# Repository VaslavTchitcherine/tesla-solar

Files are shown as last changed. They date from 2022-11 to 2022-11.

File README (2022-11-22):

TESLA MODULE SOLAR POWER SYSTEM

This describes how to use Tesla Model S battery modules in an offgrid
solar power system, comprised of:

1) Any number (between 1 and 63) of Tesla Model S battery modules connected in parallel.
The prototype system has two modules from a P100D, each 6.4 kWh. 

2) A solar charge controller.
Victron BlueSolar 24V MPPT 100/50 Charge Controller (100V, 50A maximum input).
It is essential that the controller allows you to set the maximum charge voltage
to something suitable for the Tesla modules (i.e. never more than 25.2V).

3) An inverter for AC output.  Modern pure sine wave inverters
are quite efficient.  Ideally you want one with an adjustable
(or no) low voltage cutoff, as the Tesla modules are usable down to about 18V,
lower than many other battery chemistries.

4) Two hall effect current sensors (Allegro ACS758) to measure panel
current and battery current.  The battery current can be positive or negative,
depending on whether the battery is charging or discharging.  Panel current
is never less than zero.

5) A pair of DC solid state relays (Crydom D06D100) to disconnect the panels
if the battery modules are overvoltage, and disconnect the battery modules if they
are undervoltage.

6) A Raspberry Pi Zero W with a custom Pi hat.  Python code on the Pi:
	a) Communicates with the Tesla modules using a 612500 baud serial loop.
	b) Reads current sensors using a 16 bit dual A/D (ADS1115)
	c) Monitors and logs voltages, currents, and battery temperatures.
	d) Serves plots of the logs on a web page (using the dygraphs.js library)
	d) Controls the SSR disconnects via GPIO
	e) Balances batteries at both the module and cell level, by switching in
	   shunt resistors on the Tesla BMS boards when necessary.

7) Optionally, an AC SSR (Opto22 240A45) to disconnect the output of the 
inverter from the load.  Some inverters enter an error state if there
is an AC load when DC input power is applied.  This SSR disconnects the
load from the output of the inverter until several seconds after the
inverter is connected to the battery bank by the respective DC SSR.

The Pi is powered directly (through a small fuse) from the
battery modules, using an LM2596-based buck converter.
It is important that the Pi remain powered through
an undervoltage condition, so that it can close the SSR to reconnect the
battery modules to the inverter once they are sufficiently charged so that
they are no longer undervoltage. 

(BLOCK DIAGRAM)
(PHOTOS of system and control box)

Tesla Battery Modules
---------------------

All Telsa Model S battery modules have 6 series-connected groups
of a large number of 18650 LiOn cells in parallel.
For example, the P100D module has 516 18650 LiOn cells per module, connected 6s86p.

A fully charged 18650 cell is 4.2V, so 4.2*6 = 25.2V is the maximum voltage
of a fully charged module.  It is better to set the float voltage on the
Victon charge controller for a lower voltage (e.g. 24.2V) to both
allow some headroom for unbalanced cells and to avoid stressing the cells.
The Panasonic NCR18650B data sheet shows a knee at around 3.0V on the
discharge characteristics graph, so 3.0*6 = 18V can be considered the minimum usable voltage of a module.

The Tesla module has a BMS board, containing:
C8051F536 microprocessor
Silicon Labs 8642ED RF isolator
TI BQ76PL536A Lithium ion battery monitor (for 6 cells)
158 ohm resistors, 4 in parallel, for a 39.5 ohms of bleed for balancing

These modules communicate via 612500 baud serial, with the serial connection
arranged in a loop (Wiring2.png).  What is meant by a loop?
Each module receives serial data on RX (pin 2) and transmits it on TX (pin 4).
There are two separate channels that are not connected to each other.
So any data intended for the entire system goes to the first module, which then retransmits it
from its TX to the input RX on the next module in the chain.

Connectors for Tesla modules are:
	Molex 15-97-5101 CONN RCPT 10POS DUAL MINI-FIT (Digikey WM4772-ND)
and the pins are:
	Molex 39-00-0038 CONN TERM FEMALE 18-24AWG TIN (Digikey WM2501CT-ND)

Using the Raspberry Pi (Pi Zero W, Pi3, Pi3B+) UART
---------------------------------------------------

UART0_TXD is GPIO 14, pin 8 on GPIO header
UART0_RXD is GPIO 15, pin 10 on GPIO header

By default the the primary UART (/dev/serial0) is used for a console.
Use the raspi-config utility to disable this.
Select option 5, Interfacing options, then option P6, Serial, and select No.

The BCM2837 on a recent Pi has two UARTS, but the mini UART is not suitable for
high speed serial communication, having too small a buffer and variable frequency.
To use the PL011 UART instead of the mini UART, add these lines to the /boot/config.txt file:
        dtoverlay=pi3-disable-bt
        enable_uart=1
This disables the Bluetooth module and maps the PL011 UART onto GPIO pins 14 and 15,
which appears as /dev/serial0 (a symbolic link to /dev/ttyAMA0).
Note the pi4 instructions are different:
https://di-marco.net/blog/it/2020-06-06-paspberry_pi_3_4_and_0_w_serial_port_usage/

Also, the Pi is 3.3V, and needs to interface to 5V RS232 serial levels on the Tesla modules.
For this, we use the circuit from the SparkFun bidirectional logic level converter
(https://www.sparkfun.com/products/12009) which uses a BSS138 MOSFET with pullups to
perform the level conversion.

References:
https://www.raspberrypi.org/documentation/configuration/uart.md
https://raspberrypi.stackexchange.com/questions/45570/how-do-i-make-serial-work-on-the-raspberry-pi3-pi3b-pizerow

A/D conversion
--------------

To use the ADS1115, the I2C interface has to be enabled on the Pi.
Details on how do do this using raspi-config are here:
    https://learn.adafruit.com/adafruits-raspberry-pi-lesson-4-gpio-setup/configuring-i2c

We use the Adafruit_ADS1x15 library to communicate with the ADS1115:
	sudo apt-get update
	sudo apt-get install -y python-smbus
	sudo apt-get install i2c-tools
	sudo apt-get install build-essential python-dev python-smbus git
	cd ~
	git clone https://github.com/adafruit/Adafruit_Python_ADS1x15.git
	cd Adafruit_Python_ADS1x15
	sudo python setup.py install

See:
	https://learn.adafruit.com/adafruit-4-channel-adc-breakouts
	https://github.com/adafruit/Adafruit_Python_ADS1X15
	https://learn.adafruit.com/raspberry-pi-analog-to-digital-converters/ads1015-slash-ads1115

DCDC SSR Disconnects
--------------------

A Crydom D06D100 DCDC solid state relay disconnects the panels if an overvoltage condtion
should occur (e.g. misconfiguration or failure of the charge controller).
And another D06D100 is used to disconnect the Tesla modules if an undervoltage condtion
should occur (e.g. too much power consumption or insufficient sunshine).

The SSRs dissipate less power than would
mechanical contactors, except briefly during infrequent conditions of very high current draw.

A mechanical contactor such as a Gigavac of suitable current capacity draws 0.28 A for a
24 VDC coil voltage, i.e. 6.7 W at all times.
With 0.005 ohm Rds(on) the Crydom D06D100 SSR relay at draws
	I^2R = 100 * 100 * 0.005 = 12.5 W
at 100A.  But in practice I never pull more than 40A from my batteries,
and generally only a few amps.   So this Crydom DC SSR (which I
understand to be a pair of mosfets with optoisolated driver in a
convenient package) wastes less power than keeping the electromagnet for
a contactor powered.

Note that the Crydom D06D100 is expensive, but I would not trust a
(possibly counterfeit) Fotek to handle the current.

Battery Balancing
-----------------

Despite widespread disinformation and confusion on the subject, battery
balancing is simple.

The Tesla BMS board has shunt resistors, one per cell, which can be independently switched in to 
bleed charge from any of the 6 cells in a battery module.   This "top balancing" should be done whenever
any cell's voltage is sufficiently much higher than that of the second
highest cell in the module.

Analogously, at a module level, all 6 bleed resistors for a module should be
switched in when the voltage for that module is sufficiently much higher than that of the second
highest module.

This balancing is performed by the Python code, voltage thesholds for balancing are
parameters stored in global variables.

Logging and Plotting
--------------------

The Python code writes 3 log files, the names of which must be supplied as positional
command line parameters.

This first of these log files is a CSV file, fields of which are respectively:
datetime in ISO format (YYYY-MM-DD HH:MM:SS)
	module 1 Soc (%)
	module 1 Voltage (V)
	module 1 Temperature 1 (degrees C)
	module 1 Temperature 2 (degrees C)
	module 1 maximum cell imbalance (V)
	module 2 Soc (%)
	module 2 Voltage (V)
	module 2 Temperature 1 (degrees C)
	module 2 Temperature 2 (degrees C)
	module 2 maximum cell imbalance (V)
	.
	.
	.
		module n Soc (%)
	module n Voltage (V)
	module n Temperature 1 (degrees C)
	module n Temperature 2 (degrees C)
	module n maximum cell imbalance (V)
	battery current (A)
	panel current (A)

The second log file is blank delimited file, with a timestamp and fields for the voltage of each cell.

The third log file contains warnings, such as over and undervoltage conditions.

Plots of fields the first log file can be made using the dygraphs.js library (http://dygraphs.com).
Specify /var/www/html/log.csv as the first command line argument to tesla.py and use
index.html as the home page.

Here is sample output.
You can see I had 3 espressos today.

Pi Hat
------

Eagle files and BOM with Digikey part numbers for the Pi Hat.

Thanks
------

Thanks to everyone who did the hard work of reverse engineering the Tesla modules, and
to Ulrich Gall for the original Python code.
http://evtv.me/2017/03/tesla-battery-victory-lap/
https://github.com/collin80/TeslaBMS
https://github.com/jarrod89/TeslaBMS
https://github.com/tomdebree/TeslaBMS

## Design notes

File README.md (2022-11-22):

# tesla-solar
Tesla S modules for off-grid solar power

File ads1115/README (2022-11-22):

hacked examples from /root/Adafruit_Python_ADS1x15/examples

https://learn.adafruit.com/adafruit-4-channel-adc-breakouts
https://github.com/adafruit/Adafruit_Python_ADS1X15
https://learn.adafruit.com/raspberry-pi-analog-to-digital-converters/ads1015-slash-ads1115

Note we have ADDR pin to GND, so i2c slave addr is 1001000 (0x48)

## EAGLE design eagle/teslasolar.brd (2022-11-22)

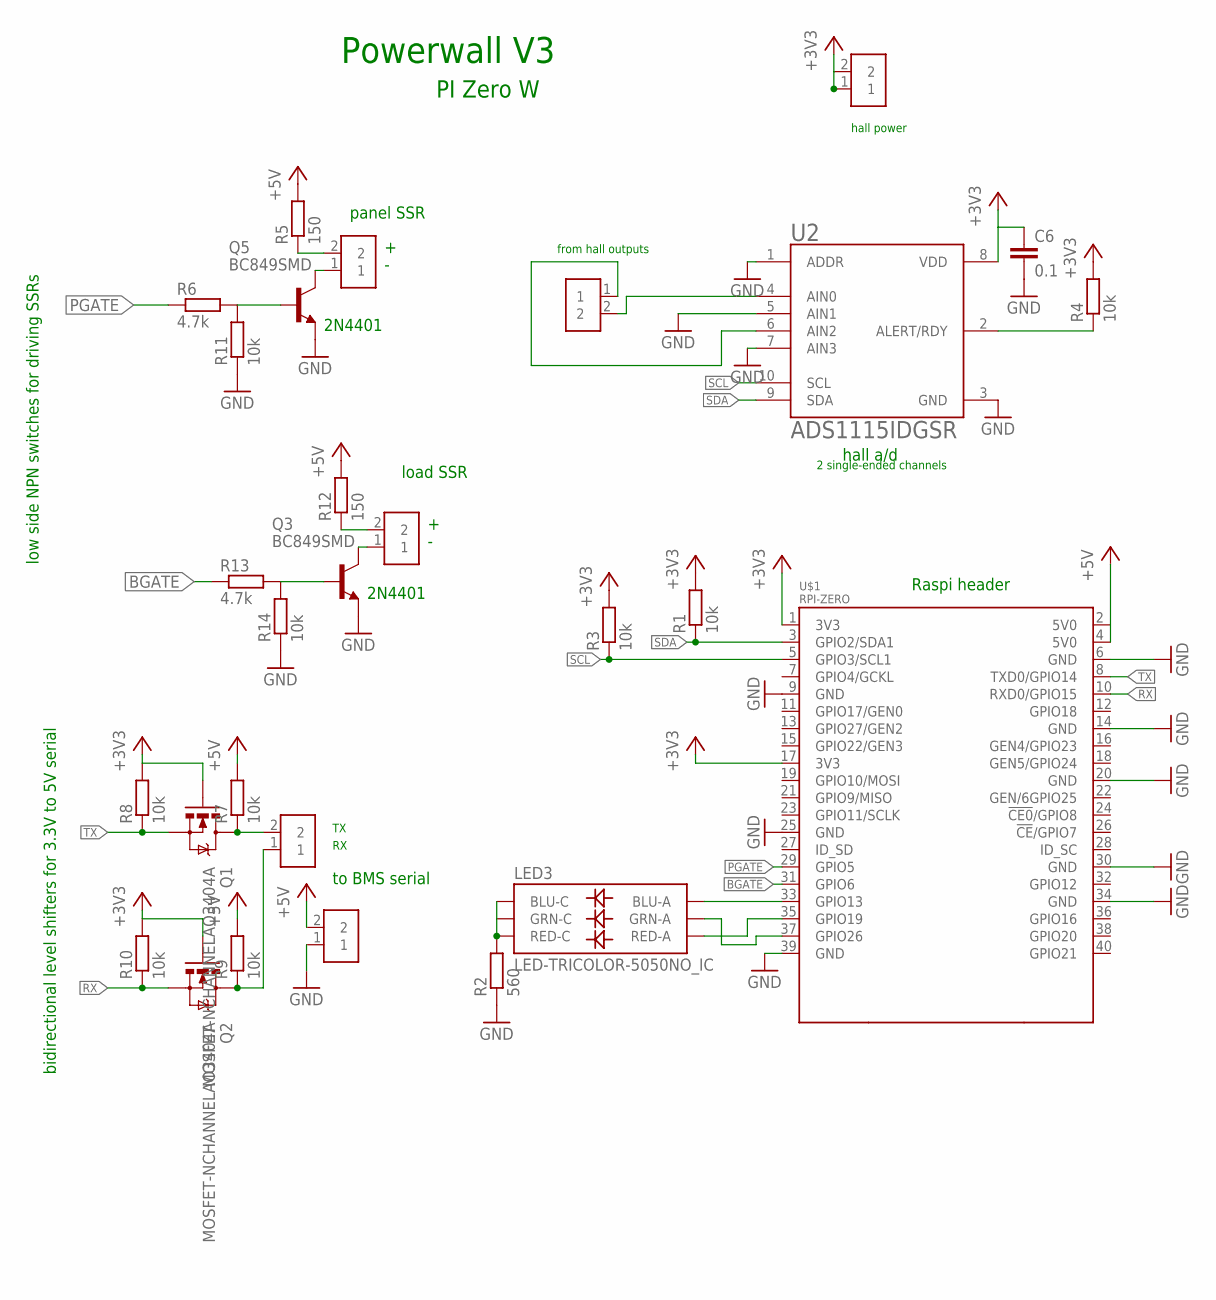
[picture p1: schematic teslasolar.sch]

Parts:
C6: 0.1; C0603
J1, J2, J3, J4, J5, J6: 282834-2; CONN_282834-2
LED3: LED-TRICOLOR-5050NO_IC; LED-TRICOLOR-5050
Q1, Q2: MOSFET-NCHANNELAO3404A; SOT23-3
Q3, Q5: BC849SMD; SOT23-BEC
R1, R3, R4, R7, R8, R9, R10, R11, R14: 10k; R0603
R2: 560; R0805
R5, R12: 150; R0603
R6, R13: 4.7k; R0603
U2: ADS1115IDGSR; SOP50P490X110-10N
U$1: RPI-ZERO; RASPBERRYPI_BASTELSTUBE_V13_RASPI_BOARD_B+_FULL

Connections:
3V3@2: U$1.17 (3V3)
+3V3: C6.1, J4.1, J4.2, Q1.1 (G), Q2.1 (G), R1.2, R3.2, R4.2, R8.2, R10.2, U2.8 (VDD), U$1.1 (3V3)
+5V: J5.2, R5.2, R7.2, R9.2, R12.2, U$1.2 (5V0), U$1.4 (5V0)
BGATE: R13.1, U$1.31 (GPIO6)
GND: C6.2, J5.1, Q3.E, Q5.E, R2.1, R11.1, R14.1, U2.1 (ADDR), U2.3 (GND), U2.5 (AIN1), U2.7 (AIN3), U$1.6 (GND), U$1.9 (GND), U$1.14 (GND), U$1.20 (GND), U$1.25 (GND), U$1.30 (GND), U$1.34 (GND), U$1.39 (GND)
unnamed: LED3.3 (BLU-A), U$1.33 (GPIO13)
unnamed: LED3.2 (RED-A), U$1.35 (GPIO19)
unnamed: LED3.1 (GRN-A), U$1.37 (GPIO26)
unnamed: LED3.4 (BLU-C), LED3.5 (RED-C), LED3.6 (GRN-C), R2.2
unnamed: J3.2, Q1.3 (D), R7.1
unnamed: J3.1, Q2.3 (D), R9.1
unnamed: J1.2, R5.1
unnamed: J6.2, R12.1
unnamed: J1.1, Q5.C
unnamed: Q5.B, R6.2, R11.2
unnamed: J6.1, Q3.C
unnamed: Q3.B, R13.2, R14.2
unnamed: R4.1, U2.2 (ALERT/RDY)
unnamed: J2.1, U2.6 (AIN2)
unnamed: J2.2, U2.4 (AIN0)
PGATE: R6.1, U$1.29 (GPIO5)
RX: Q2.2 (S), R10.1, U$1.10 (RXD0/GPIO15)
SCL: R3.1, U2.10 (SCL), U$1.5 (GPIO3/SCL1)
SDA: R1.1, U2.9 (SDA), U$1.3 (GPIO2/SDA1)
TX: Q1.2 (S), R8.1, U$1.8 (TXD0/GPIO14)

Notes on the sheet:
hall a/d
PI Zero W
to BMS serial
2 single-ended channels
from hall outputs
hall power
Raspi header
panel SSR
Powerwall V3
2N4401
bidirectional level shifters for 3.3V to 5V serial
low side NPN switches for driving SSRs
load SSR

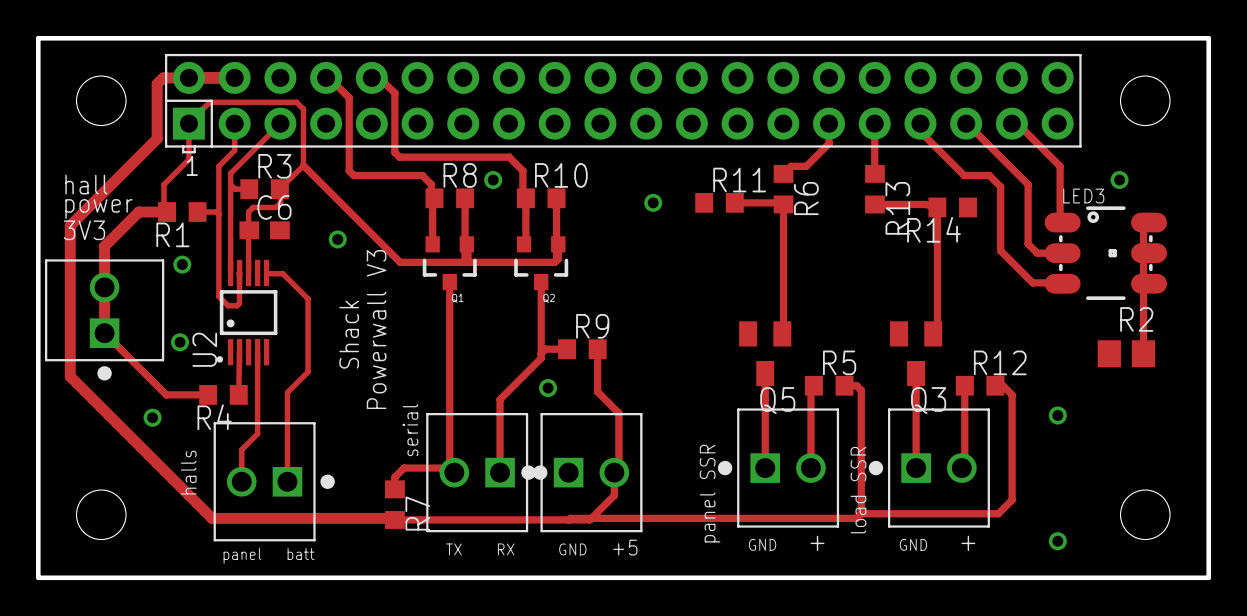
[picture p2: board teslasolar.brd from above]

Board: 2 copper layers, 65.0 x 30.0 mm, 28 parts (0 on the bottom side), 24 nets.

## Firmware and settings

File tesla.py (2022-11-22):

#!/usr/bin/python
#
# tesla.py
#
# Pi Zero W monitor for homebrew solar system using Tesla modules.
# 1) Read and log voltage and temperature data from the Tesla modules.
# 2) A/D conversion of battery and solar panel current hall sensors.
# 3) GPIO for solid state relays for battery and solar panel connects.
# Mandatory command line positional arguments are:
# 	log file (for web display by dygraph.js)
# 	log file with all 12 cell voltages
#	log file for errors
# Example:
#	nohup tesla.py /var/www/html/log.csv /tmp/cellvolts /tmp/error &
#

import serial
import time
import math
import sys
import select
import argparse
import Adafruit_ADS1x15		# 16 bit A/D for hall current sensors
from gpiozero import LED	# for GPIO control of SSR disconnects
import atexit

# register values for tesla bms boards
REG_ADDR = 0		# board address [1,62] is at register 0
REG_GPAI = 1		# general purpose i/o
REG_ALERT_STATUS = 0x20
REG_ADC_CTRL  = 0x30
REG_IO_CTRL   = 0x31
REG_BAL_CTRL  = 0x32	# to set balance timeout (?)
REG_BAL_TIME  = 0x33	# to set state of balancing resistors
REG_ADC_CONV  = 0x34
REG_ADDR_CTRL = 0x3B

# voltage threshold at which balancing begins (WHAT SHOULD THIS BE?)
balancethresh = 0.1

# log record emitted how frequently (sec)
loginterval = 5

# epoch time when last log record emitted
lastemit = 0

# exponential moving average smoothing period
emaperiod = 10		# 1 for no smoothing
emafactor = 2.0/(emaperiod+1.0)

# initialization of the ema-smoother values
batt_current = 0
panel_current = 0

# module voltage extrema (for state of charge computation)
#maxv = 24.6;   # 24.6V is 100% SoC (4.1V per cell)
maxv = 24.0;
###minv = 18.6;   # 18.6V is 0% SoC (3.1V per cell)
minv = 19.8;   # 19.8V is 0% SoC (3.3V per cell)

# called when terminated with ^C or kill
@atexit.register
def goodbye():
	print "Terminated"
	# turn off both SSRs
	load_connect.off()
	panel_connect.off()

# log to error file
def warn(s):
	print("WARNING: {}".format(s))
	logerrorsfile.write(time.strftime("%Y-%m-%d %H:%M:%S "))
	logerrorsfile.write(s)

def hex(arr):
	return(''.join(' {:02x}'.format(x) for x in arr))

# convert raw thermistor data to degrees C
def tempCalc(b1,b2):
	t = 1000 * (1.78*float(33046) / (int(b1) * 256 + int(b2) + 2)  - 3.57)
	if t <= 0:
		warn("Bad temperature reading: b1={}, b2={}, val = {}".format(b1,b2,t))
	t = 1 / (0.0007610373573 + 0.0002728524832 * math.log(t) + 0.0000001022822735 * (math.log(t)**3))
	return(t - 273.15)		  

# return crc byte for a specified byte array
# Note: genCRC([x1, x2, ... xn]) == 0 iff genCRC([x1,x2,...xn-1]) == xn
def genCRC(data):
	generator = 7
	crc = 0
	for b in data:
		crc = crc ^ b 
		for i in range(8):
			if (crc & 0x80) != 0:
				crc = ((crc << 1) ^ generator) & 255
			else:
				crc <<= 1
	return(crc) 

# class for one module
class BMSBoard:
	def __init__(self, bus, address):
		self.bus = bus
		self.address = address
		self.balancemask = 0		# bitmask for the 6 balancing resistors
		#log("Created BMSBoard {}.".format(address))

	def __str__(self):
		s = "BMS Board {} ".format(self.address)
		s += "Alerts: {}, Faults: {} ".format(self.alerts, self.faults)
		s += ", Cell Over Voltage Faults: {}, Under: {} ".format(self.cov_faults, self.cuv_faults)
		s += ", Cell Voltages = "+"".join("{0:.4f}V ".format(v) for v in self.cellVolt)
		s += ", Temps = {0:.2f}C {1:.2f}C".format(self.temperatures[0],self.temperatures[1])
		return s

	# Called to get new values (voltages, temperatures) from a module.
	# Also reads status, we probably don't care about this, as our program monitors module parameters.
	def update(self):
		self.readStatus()
		self.readModuleValues()
		# total voltage of this module
		self.moduleVolt = self.cellVolt[0] + self.cellVolt[1] + self.cellVolt[2] + self.cellVolt[3] + self.cellVolt[4] + self.cellVolt[5];
		# compute state of charge using voltage extrema
		self.soc = 100 * (self.moduleVolt - minv) / (maxv - minv)
		self.balance();		# activate balancing resistors as necessary
		#log("Board {} status: {}".format(self.address,self))
		# check voltages and set SSRs appropriately
		if ( self.moduleVolt >= minv and self.moduleVolt <= maxv ):
			load_connect.on()
			panel_connect.on()
		# low voltage, disconnect load but keep panels connected
		elif ( self.moduleVolt < minv ):
			warn('low voltage disconnect, load off')
			load_connect.off()
			panel_connect.on()
		# high voltage, disconnect panels but keep load connected
		elif ( self.moduleVolt > maxv ):
			warn('high voltage disconnect, panels off')
			load_connect.on()
			panel_connect.off()

	# dump board data to log files
	def dump(self):
		logfile.write("{0:.2f},{1:.4f},{2:.1f},{3:.1f},{4:.6f},".format(self.soc,self.moduleVolt,self.temperatures[0],self.temperatures[1],self.imbalance))
		# also write cell voltages to another log file
		logcellsfile.write("{0:.4f} {1:.4f},{2:.4f} {3:.4f} {4:.4f} {5:.4f} ".format(self.cellVolt[0],self.cellVolt[1],self.cellVolt[2],self.cellVolt[3],self.cellVolt[4],self.cellVolt[5]))

	# Determine the mask for balancing resistors
	# The resistor is switched in for a cell if its voltage is sufficiently higher than all others.
	# Only one resistor will ever be switched in at any given time.
	def balance(self):
		# determine highest cell voltage and its location
		high = 0.0
		for i in range(6):
			if ( self.cellVolt[i] > high ):
				high = self.cellVolt[i]
				highat = i;
		# determine 2d highest cell voltage
		high2 = 0.0;
		for i in range(6):
			if ( self.cellVolt[i] > high2 and i != highat ):
				high2 = self.cellVolt[i]

		# imbalance is difference between highest and second highest cell
		self.imbalance = high-high2

		# is the imbalance sufficiently large to bleed it?
		mask = 0;
		if ( self.imbalance > balancethresh ):
			mask = 1<<(5-highat);
		# if the mask has changed, set state of resistors
		if ( mask != self.balancemask ):
			self.setbalance(mask)
			self.balancemask = mask		

	# Called with a 6 bit mask to set balancing resistors on/off
	def setbalance(self,mask):
		# 5 second balance timeout
		# if not triggered to balance it will stop after 5 seconds  (???)
		# or will or only balance for 5 seconds?
		self.send_and_receive_reply(REG_BAL_TIME, 5, True)
		# send the mask
		self.send_and_receive_reply(REG_BAL_CTRL, mask, True) 
		# XXX readback register values to be sure they got set???

	def send_and_receive_reply(self, command, param, isWrite = False):
		return(self.bus.send_and_receive_reply_to(self.address,command, param, isWrite))

	# poll for status of a module
	def readStatus(self):
		r = self.send_and_receive_reply(REG_ALERT_STATUS,4)
		self.alerts,self.faults,self.cov_faults, self.cuv_faults = r[3:7]

	# poll for values (voltages, temperatures) from a module
	def readModuleValues(self):
		# ADC Auto mode, read every ADC input we can (Both Temps, Pack, 6 cells)
		# sets which channels we read
		self.send_and_receive_reply(REG_ADC_CTRL, 0b00111101, True)		# 0x3D
		# enable temperature measurement VSS pins
		self.send_and_receive_reply(REG_IO_CTRL, 0b00000011, True)		# 0x03
		# start all ADC conversions		
		self.send_and_receive_reply(REG_ADC_CONV, 1, True)
		# request the 18 byte (0x12) data record
		r = self.send_and_receive_reply(REG_GPAI,0x12, False)

		# we expect to have read 22 bytes, the 18 byte data record plus:
		#	3 bytes of header (address, command, length)
		#	1 byte footer (crc)
		if (len(r) != 22):
			warn("readModuleValues expected 22 bytes but got {}".format(len(r)))
			return

		# payload is 2 bytes gpai, 2 bytes for each of 6 cell voltages, 
		# 2 bytes for each of two temperatures (18 bytes of data)
		self.cellVolt = [(r[5 + (i * 2)] * 256 + r[6 + (i * 2)]) * 0.000381493 for i in range(6)]
		self.temperatures = [tempCalc(r[17],r[18]),tempCalc(r[19],r[20])]


# class for the entire set of up to 63 modules
class BMSBus:
	def __init__(self):
		self.findBoards()
	
	# see if any module [1,62] responds
	def findBoards(self):
		self.boards = []
		for i in range(1,62):
			# read address of module i, one byte
			r = self.send_and_receive_reply_to(i,REG_ADDR,1,False)
			if len(r) != 0:
				if not (r[0] == 2*i and r[1] == 0 and r[2] == 1):
					print("Unexpected response!")
				if len(r) > 3:
					if not (r[4] > 0) :
						warn("r4 was = {}".format(r[4]))
					else:
						print("BMSBoard {} responded {}".format(i,hex(r[3:])))
						self.boards.append(BMSBoard(self,i))
			time.sleep(0.005)

	# PERHAPS WARN IF UNEXPECTED # OF BOARDS RESPONDED?

	# update status and values for all boards
	def updateBoards(self):
		for board in self.boards:
			board.update()

	# dump values for all boards to log files
	def dumpBoards(self):
		for board in self.boards:
			board.dump()

	# initialize all boards:
	#	balancing resistors off
	#	clear alerts()?
	# NEEDED?
	def resetBoards(self):
		for board in self.boards:
			board.setbalance(0);

	def send_and_receive_reply_to(self, destination, command, param, isWrite = False):
		# huh?  The dest changes if isWrite ???
		dest = 2*destination +1 if isWrite else 2*destination
		payload = bytearray([dest, command, param])
		if isWrite: 
			# original code was doing weird things that I think amounted to nothing. So I simplified.
			crc = genCRC(payload)
			###log("isWrite, therefore adding CRC = {}".format(crc))
			payload.append(crc)
		ser.write(payload)
		#log("Sent: {}".format(hex(payload)))
		time.sleep(0.02)
		reply=[]
		while(ser.inWaiting()):
			reply.append(ord(ser.read()))
		# check crc
		if isWrite and genCRC(reply) != 0:
			warn("CRC error: Reply was {}".format(hex(reply)))
		return(reply)

##########################
# main program

# check for correct number of mandatory command line arguments
if ( len(sys.argv) != 4 ):
        print "Usage: tesla.py <main_logfile> <cellvolts_logfile> <error_logfile>"
        sys.exit(-1)

# open the serial port, hardware serial GPIO14 and GPIO15 on Pi Zero W.
# Must use raspi-config, Interfacing Options, P6 to disable console and allow access.
# Also add the line:
#	dtoverlay=pi3-disable-bt
# to /boot/config.txt so the PL011 UART is mapped to GPIO14 and GPIO15 and appears as /dev/serial0
try:
	ser = serial.Serial( # set parameters
		port='/dev/serial0',	# for hardware serial port (GPIO14 and GPIO15 on Pi Zero W)
		#port='/dev/ttyUSB0',	# for adafruit ftdi cable
		baudrate=612500,
		timeout=1
	)
	ser.isOpen() # try to open port

except IOError: # if port is already opened, close it and open it again
	try:
		ser.close()
		ser.open()
		print ("port was already open, was closed and opened again")
	except: #ser object doesn't even exist? must be a port setting fault
		ser=False
		print ("Check port settings!")
		exit(-1);

# parse command line arguments 
parser = argparse.ArgumentParser(description='tesla solar controller')
parser.add_argument("log")
parser.add_argument("logcells")
parser.add_argument("logerrors")
args = parser.parse_args()

# try to open all 3 log files for write (append?)
logfile = open(args.log, 'w')
logcellsfile = open(args.logcells, 'w')
logerrorsfile = open(args.logerrors, 'w')

# find all the modules, also calls update once for each
bms = BMSBus()

# balancing resistors off, clear alerts
bms.resetBoards()

# create an ADS1115 ADC (16-bit) instance
adc = Adafruit_ADS1x15.ADS1115()

# GPIO lines to control the load and solar panel SSR connects
panel_connect = LED(5)	# GPIO 5 is pin 29 on the Pi header
load_connect = LED(6)	# GPIO 6 is pin 31 on the Pi header

# colors of the indicator LED
led_red = LED(19)
led_green = LED(26)
led_blue = LED(13)

# indicator LED state
led_green_on = 0

# load and solar panels are both disconnected until we are sure voltages are OK
load_connect.off()
panel_connect.off()

while True:
	# read boards, update internal state
	bms.updateBoards()

	# local time (in a format that js can parse)
	timestring = time.strftime("%Y-%m-%d %H:%M:%S")

	# write to log file
	logfile.write(timestring)
	logfile.write(',')

	# write to cell-level log file
	logcellsfile.write(timestring)
	logcellsfile.write(' ')

	# dump data from boards (to both log files)
	bms.dumpBoards()

	# Read ACS758 hall sensor(s) to obtain currents
	# Subtract a/d offset, scale into amps, and ema filter
	# (THE 0.01786 COEFFICIENT TO SCALE INTO AMPS IS APPROXIMATE, SHOULD RECALIBRATE THIS)
        rawadc = 0.01786 * (adc.read_adc(0, gain=1) - 8681)
        batt_current = emafactor * rawadc + (1.0 - emafactor) * batt_current

	# write battery current to log file (negated)
	logfile.write("{0:.3f}".format(-batt_current))

	# newlines and flushing of logfiles
	logfile.write("\n")
	logcellsfile.write("\n")
	logfile.flush()
	logcellsfile.flush()
	logerrorsfile.flush()

	# current epoch time
	now = time.time()

	# inter-record delay
	wait = loginterval - (now - lastemit)

	if ( wait > 0 ):
		time.sleep(wait)

	lastemit = time.time()

	# toggle status LED
	if ( led_green_on ):
		led_green_on = 0
		led_green.off()
	else:
		led_green_on = 1
		led_green.on()

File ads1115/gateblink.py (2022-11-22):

#!/usr/bin/python
#
# gateblink.py
# Test reading hall sensors on IN0 and IN2 of ADS1115, while blinking mosfets
#

from time import sleep
import Adafruit_ADS1x15
from gpiozero import LED

# create an ADS1115 ADC (16-bit) instance
adc = Adafruit_ADS1x15.ADS1115()

# to MCP1407 MOSFET drivers
panelswitch = LED(5)
batteryswitch = LED(6)

# Choose a gain of 1 for reading voltages from 0 to 4.09V.
# Or pick a different gain to change the range of voltages that are read:
#  - 2/3 = +/-6.144V
#  -   1 = +/-4.096V
#  -   2 = +/-2.048V
#  -   4 = +/-1.024V
#  -   8 = +/-0.512V
#  -  16 = +/-0.256V

while True:
	print 'on'
        panelswitch.on()
        batteryswitch.on()
	panels = adc.read_adc(0, gain=1)
	battery = adc.read_adc(2, gain=1)
	print panels,battery
        sleep(1)

        print 'off'
        panelswitch.off()
        batteryswitch.off()
	panels = adc.read_adc(0, gain=1)
	battery = adc.read_adc(2, gain=1)
	print panels,battery
        sleep(1)

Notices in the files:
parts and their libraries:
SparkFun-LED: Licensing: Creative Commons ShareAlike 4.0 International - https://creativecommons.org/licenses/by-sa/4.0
